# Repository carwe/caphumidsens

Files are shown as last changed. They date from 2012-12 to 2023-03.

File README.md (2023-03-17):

ARCHIVED on github -> migrated to codeberg: https://codeberg.org/carwe/caphumidsens

<b>code not usable due to never debugged bugs</b>

<b>code not usable due to never debugged bugs</b>

<b>code not usable due to never debugged bugs</b>

<b>code not usable due to never debugged bugs</b>

caphumidsens
============
Contains EAGLE-files for a pcb to convert soil moisture into frequency.

There are various revisions of the board:

classic design with NE555
-------------------------

###caphumidsens rev1
This was more or less a test, if the idea is working. It is quite big and unoptimized. Also the design of the capacitator is unnecessary complex.<br>
You need one NE555 (or CMOS-equivalent like TLC555) in SO-8, the other parts are of size 0805. C1=10nF; C2=100nF; R1=R2=120kOhm; D1=1N4148<br>
The chosen values let the output oscillate with around 74kHz, when dry and in air, down to around 4kHz, when the cap-part of the board is put into pure water, if you have chosen the TTL-555.

###caphumidsens rev2
...died an early death and was never physically fabricated.

###caphumidsens rev3
...is space-optimized and the components are nicely placed in a row, the draw-back is, they are too close - unfortuntely I had some of them fabricated, so it needed some fiddling to solder. <b>Do not use this layout.</b> In the discussion about this board some ideas came along: you probably want to measure the humidity in the middle of the soil, at least not directly on the surface, where it varies most. And there should be some kind of safety-margin, you don't want to change the capacitance by moving it slightly in and out of the soil. Next design should adress this.

###caphumidsens rev4
Here the capacitator was moved, so the humidity on the surface is no longer significant. Also the parts, which were too close to each other, got more space between them.

<pre>Measurements (frequency in kHz):
                Rev1/TTL        Rev1/CMOS        Rev3/CMOS        Rev4/CMOS
air              74,9              66,8            91,6              ?
dry soil         73,1              65,3            91,3              ?
half-wet soil    64,0              52,5            73,4              ?
wet soil         13,4              17,8            37,6              ?
water             3,4               ?               ?                ?</pre>

redesign with ATtiny
--------------------

###caphumidsens rev5
Lately I discussed about the project, and it quickly became clear, that it should be possible to connect output-pins of more than one caphumidsens-pcb over a single line with a master-controller. Using a bus has clear advantages (otherwise, you have to use a dedicated line to transport each signal, of course), so I designed a first draft.

With a ATtiny25/45/85 (maybe ATtiny13A too, if the code fits into it - comparator is existent there too, and the pinout is the same) I tried to create a NE555-similar structure. A capacitator is charged to a higher voltage, then discharged to a lower voltage, and a comparator toggles the (dis-)charging.

You have to decide if you want to use the internal voltage reference or not. If yes, you have to sense the voltage with AIN1 and compare it to the internal voltage reference and AIN0 as external voltage reference. If no, you have to sense the voltage with AIN0 and compare it witho two external voltage references on ADC0-ADC3. Some time ago I wrote here you could not compare against the internal reference and the multiplexer at the same time and save a pin - which is true, but you don't need to, it just requires another layout. To use the internal voltage reference for one side of the comparison, you have to have your sense pin as negative side on AIN1, and select the internal reference for the positive side of the AC. Then compare negative side AIN1 with AIN0 as the positive side of the AC. But, this is not what I designed.

I chose to use two external voltage references, created by division of VCC, same as in 555. This way it makes no difference what exact voltage VCC is, it can even change, the resulting frequency is independent. So you sense the voltage on AIN0 as positive side of the AC, and the multiplexer as negative side, and switch the input of the multiplexer as you charge (ADC1) and discharge (ADC2).

Pin 6 is set to VCC or GND to charge or discharge the capacitator, pin 5 senses the voltage and compares it to pin 3 or 7. On pin 1 (and maybe pin 2, if clock-ínput is not needed) you can talk a protocol you like - a simple frequency like the NE555 or something more complex, maybe pulling the line low against a central pull-resistor (I2C-like), sending your ID (stored in EEPROM) followed by the measured capacity. After you have written out a bit of your ID, you read it back, if another sensor is sending too (pulling the line dominates leaving the line alone, so the ID with the most "pulling bits" is the highest, CAN-like). The frequency of the messages is low enough, so that collisions should hardly occur, and if, you simply repeat your message.

Pin 1 is the reset/debugwire-pin too, so you can use debugwire to program the harder part of measuring the capacity, as you don't need the output-pin during this time. I have added small capacitators to even out the reference voltages, if that is necessary.

In the next days, I should receive some of them from the manufacturer.

Update five years later, 2017: yes I got them. and then I forgot them. And, I would not use Eagle anymore. Never again. Took me an hour to find an old version I could use with my licence, it brought me to tears what happened to this program after being bought by Autodesk. Everybody warned me to use this nonfree software, and I thought "whatever... works for me." - then reality hit.

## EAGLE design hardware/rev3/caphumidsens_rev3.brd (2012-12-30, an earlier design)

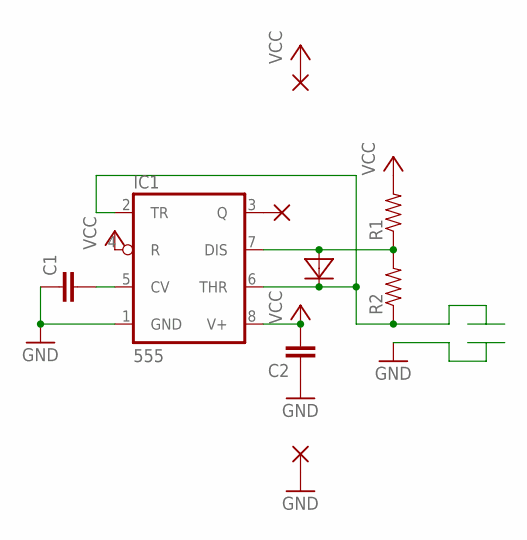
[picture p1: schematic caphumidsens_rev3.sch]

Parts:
C1, C2: CAP0805; 0805
D1: DIODE_0805
GND: WIREPADSMD2,54-5,08; SMD1,27-2,54
IC1: 555; SO08
OUT: WIREPADSMD2,54-5,08; SMD1,27-2,54
R1, R2: RESISTOR0805-RES; 0805
VCC: WIREPADSMD2,54-5,08; SMD1,27-2,54

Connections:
CAP+: D1.1 (C), IC1.2 (TR), IC1.6 (THR), R2.1
GND: C1.1, C2.1, GND.1, IC1.1 (GND)
unnamed: D1.2 (A), IC1.7 (DIS), R1.1, R2.2
unnamed: C1.2, IC1.5 (CV)
unnamed: IC1.3 (Q), OUT.1
VCC: C2.2, IC1.4 (R), IC1.8 (V+), R1.2, VCC.1

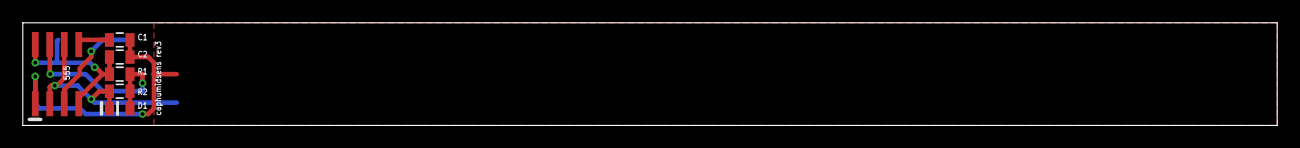
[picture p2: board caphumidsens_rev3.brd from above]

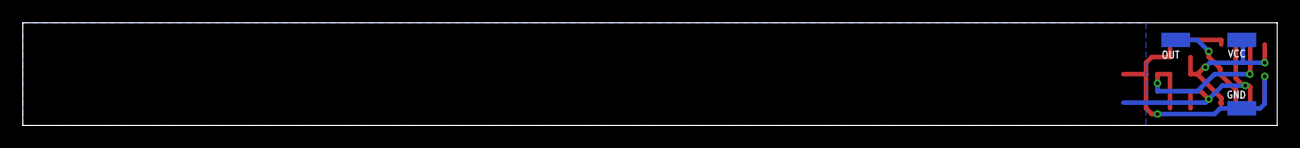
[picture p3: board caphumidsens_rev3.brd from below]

Board: 2 copper layers, 110.0 x 9.0 mm, 9 parts (3 on the bottom side), 6 nets.

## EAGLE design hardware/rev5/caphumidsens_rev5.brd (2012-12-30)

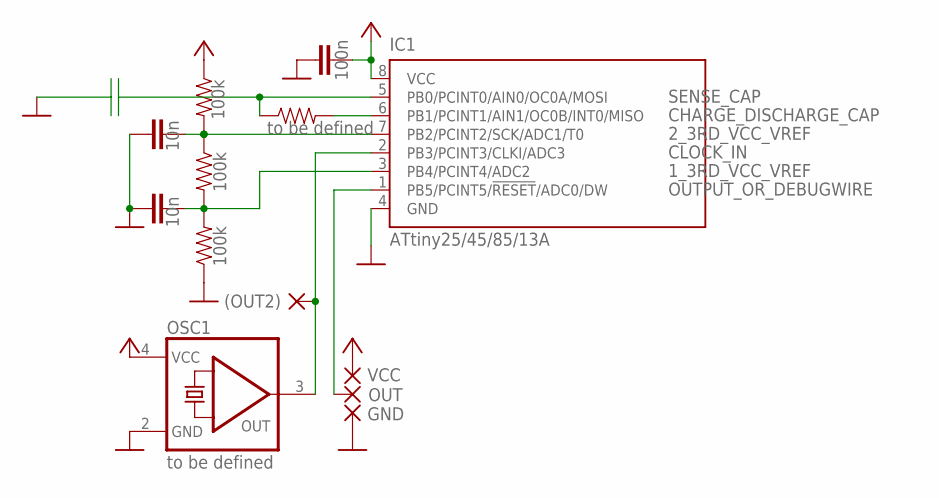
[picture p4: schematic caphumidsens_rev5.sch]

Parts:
(OUT2): WIREPADSMD2,54-5,08; SMD1,27-2,54
C1: 100n; 0805
C2, C3: 10n; 0805
GND: WIREPADSMD2,54-5,08; SMD1,27-2,54
IC1: ATtiny25/45/85/13A; 8S1
OSC1: to be defined; XO32
OUT: WIREPADSMD2,54-5,08; SMD1,27-2,54
R1, R2, R3: 100k; 0805
R4: to be defined; 0805
VCC: WIREPADSMD2,54-5,08; SMD1,27-2,54

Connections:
1_3RD_VCC_VREF: C2.1, IC1.3 (PB4/PCINT4/ADC2), R2.2, R3.2
2_3RD_VCC_VREF: C3.2, IC1.7 (PB2/PCINT2/SCK/ADC1/T0), R1.2, R2.1
CHARGE_DISCHARGE_CAP: IC1.6 (PB1/PCINT1/AIN1/OC0B/INT0/MISO), R4.2
CLOCK_IN: (OUT2).1, IC1.2 (PB3/PCINT3/CLKI/ADC3), OSC1.3 (OUT)
GND: C1.1, C2.2, C3.1, GND.1, IC1.4 (GND), OSC1.2 (GND), R3.1
OUTPUT_OR_DEBUGWIRE: IC1.1 (PB5/PCINT5/!RESET!/ADC0/DW), OUT.1
SENSE_CAP: IC1.5 (PB0/PCINT0/AIN0/OC0A/MOSI), R4.1
VCC: C1.2, IC1.8 (VCC), OSC1.4 (VCC), R1.1, VCC.1

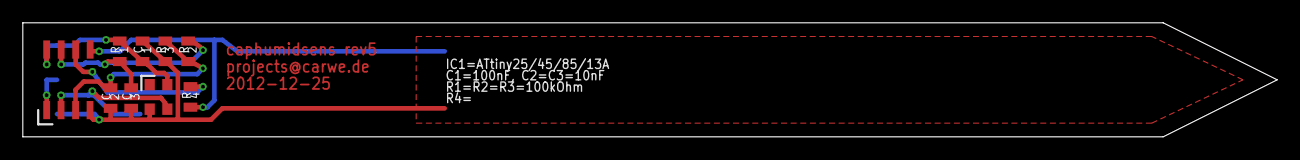
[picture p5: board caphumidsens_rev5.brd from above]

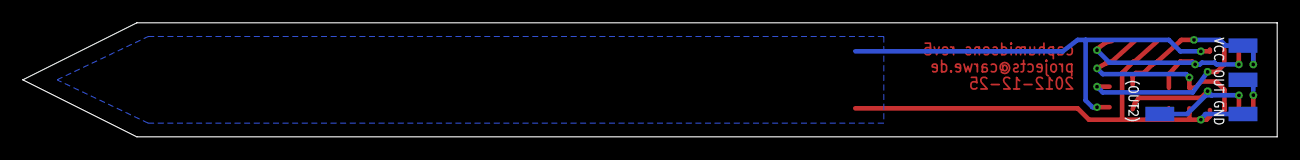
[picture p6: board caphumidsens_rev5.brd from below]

Board: 2 copper layers, 110.0 x 10.0 mm, 13 parts (4 on the bottom side), 8 nets.

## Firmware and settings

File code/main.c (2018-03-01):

// carwe 2017
// code for caphumidsens on Digistumb (ATtiny85)
// with internal bandgap as voltage reference

#define F_CPU 8000000UL
#include <stdbool.h>
#include <avr/io.h>
#include <avr/interrupt.h>
#include <util/delay.h>
#include "BitIO.h"

void AC_setup();
void CAP_charge();
void CAP_discharge();
void ACinterrupt_handling();
void TIM_setup(char);

// on AtTiny25/45/85/13A only Port B exists
#define PIN_CHARGE	2	// as digital output
#define PIN_SENSE	0	// must be on opposite side of multiplexer-input in analog comparator -> AIN0 on AtTiny13A/25/45/85, when usage of internal voltage reference wished
				// must not be AIN0, when two external reference voltages will be used
//#define PIN_VREF_1_3	0	// pin must be usable by analog comparator, maybe via multiplexer // can be substituted with internal voltage reference, when above conditions for PIN_SENSE given
#define PIN_VREF_2_3	1	// pin must be usable by analog comparator, maybe via multiplexer
#define PIN_OUTPUT	3	// as digital output, for $protocol
#define PIN_OUTPUT2	4	// as digital output, for $protocol


volatile char AC_interrupt   = 0;	// 1 when ISR signals voltage equality
volatile int  AC_interrupts  = 0;	// hold the interrupts so far
volatile char CAP_charging   = 1;	// 1==charging, 0==discharging
volatile int  CAP_capacity   = 0;	// hold the interrupts per gate time
         char CAP_countAmax  = 255;	// CAP_countAmax * CAP_countBmax should be CPU cycles per gate time // and define how long charge/discharge-cycles will be added up
         int  CAP_countBmax  = 15000;	// ^
volatile int  CAP_countB     = 0;	// ^
// count from 0 to CAP_countAmax * CAP_countBmax, sum up the oscillations of the charge/discharge-cycle in AC_interrupts, and copy to CAP_capacity at the end

void main() {
	BIT_BOOL_SET(&DDRB,PIN_CHARGE,1);	// set pins as outputs
	BIT_BOOL_SET(&DDRB,PIN_OUTPUT,1);	// ^
	BIT_BOOL_SET(&DDRB,PIN_OUTPUT2,1);	// ^

	BIT_BOOL_SET(&DIDR0,PIN_SENSE,1);	// disable digital input hardware of analog inputs
//	BIT_BOOL_SET(&DIDR0,PIN_VREF_1_3,1);	// ^
	BIT_BOOL_SET(&DIDR0,PIN_VREF_2_3,1);	// ^


	// let the LEDs blink two times to signal the end of the bootloader
	BIT_BOOL_SET(&PORTB,PIN_OUTPUT,0);
	BIT_BOOL_SET(&PORTB,PIN_OUTPUT2,0);
	_delay_ms(100);
	BIT_BOOL_SET(&PORTB,PIN_OUTPUT,1);
	BIT_BOOL_SET(&PORTB,PIN_OUTPUT2,1);
	_delay_ms(100);
	BIT_BOOL_SET(&PORTB,PIN_OUTPUT,0);
	BIT_BOOL_SET(&PORTB,PIN_OUTPUT2,0);
	_delay_ms(100);
	BIT_BOOL_SET(&PORTB,PIN_OUTPUT,1);
	BIT_BOOL_SET(&PORTB,PIN_OUTPUT2,1);
	_delay_ms(100);
	BIT_BOOL_SET(&PORTB,PIN_OUTPUT,0);
	BIT_BOOL_SET(&PORTB,PIN_OUTPUT2,0);
	_delay_ms(100);


	AC_setup();
	TIM_setup(CAP_countAmax);
	CAP_charge();


	int time = 0;
	while (1) {
		char temp1 = 0;
//		BIT_BOOL_SET(&PORTB,PIN_OUTPUT,CAP_charging);
//		BIT_BOOL_SET(&PORTB,PIN_OUTPUT2,(CAP_countB>(CAP_countBmax/2)));
		BIT_BOOL_SET(&PORTB,PIN_OUTPUT,( ACSR & (1<<ACI) ));	// ana_comp interrupt flag
		BIT_BOOL_SET(&PORTB,PIN_OUTPUT2,( SREG & (1<<SREG_I)   ));	// global interrupt enable flag

		time+=1; if (time>=3000) { time=0; }
//		_delay_ms(10);
	}
}



ISR (ANA_COMP_vect) {
	AC_interrupt=1;
	ACinterrupt_handling();
}


void AC_setup() {
	BIT_BOOL_SET(&ACSR,ACD,0);	// enable Analog Comparator
	BIT_BOOL_SET(&ADCSRB,ACME,0);	// disable multiplexer
//	BIT_BOOL_SET(&ACSR,ACIS0,0);	// set to interrupt on any edge
//	BIT_BOOL_SET(&ACSR,ACIS1,0);	// ^
//	BIT_BOOL_SET(&ACSR,ACIE,1);	// enable AC interrupt
	sei();				// enable global interrupts
}


void CAP_charge	() {
	BIT_BOOL_SET(&ACSR,ACIE,0);		// disable AC interrupt

	BIT_BOOL_SET(&ACSR,ACBG,0);		// AIN0 as positive side
	BIT_BOOL_SET(&ACSR,ACIS0,1);		// set to trigger on raising edge
	BIT_BOOL_SET(&ACSR,ACIS1,1);		// ^

	BIT_BOOL_SET(&ACSR,ACIE,1);		// enable AC interrupt
	BIT_BOOL_SET(&PORTB,PIN_CHARGE,1);	// charge
	CAP_charging=1;
}


void CAP_discharge ()
{
	BIT_BOOL_SET(&ACSR,ACIE,0);		// disable AC interrupt

	BIT_BOOL_SET(&ACSR,ACBG,1);		// INTERNAL_VREF as positive side
	BIT_BOOL_SET(&ACSR,ACIS0,0);		// set to trigger on falling edge
	BIT_BOOL_SET(&ACSR,ACIS1,0);		// ^

	BIT_BOOL_SET(&ACSR,ACIE,1);		// enable AC interrupt
	BIT_BOOL_SET(&PORTB,PIN_CHARGE,0);	// discharge
	CAP_charging=0;
}


void ACinterrupt_handling()
{	// handle equality of voltages

	AC_interrupt = 0;
	if (CAP_charging)	// was charging
	{
		AC_interrupts++;
		CAP_discharge();
	} else {		// was discharging
		CAP_charge();
	}
}


void TIM_setup(char CAP_countAmax) {
	BIT_BOOL_SET(&TCCR0B,CS02,0);	// select clock source, 001==CLK without prescaler
	BIT_BOOL_SET(&TCCR0B,CS01,0);	// ^
	BIT_BOOL_SET(&TCCR0B,CS00,1);	// ^
	BIT_BOOL_SET(&TIMSK,TOIE0,1);	// overflow interrupt enable
	TCNT0 = 0;			// reset timer
	OCR0A = CAP_countAmax;		// set to overflow on this value
}


ISR (TIM0_OVF_vect) {
	// handle overflow of timer (every CAP_countAmax)

	CAP_countB++;
	if (CAP_countB >= CAP_countBmax)
	{
		CAP_countB = 0;
		CAP_capacity = AC_interrupts;
		AC_interrupts = 0;
	}
}

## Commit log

2012-09-15 added the eagle-files
    [caphumidsens_rev1.brd, caphumidsens_rev1.sch]
2012-11-05 added rev3-files
    [caphumidsens_rev3.brd, caphumidsens_rev3.sch]
2012-11-06 added rev2-files
    [caphumidsens_rev2.brd, caphumidsens_rev2.sch]
2012-11-11 added files for rev4 rc1
    [caphumidsens_rev4_rc1.brd, caphumidsens_rev4_rc1.sch]
2012-11-12 added files for rev4 rc2
    [caphumidsens_rev4_rc2.brd, caphumidsens_rev4_rc2.sch]
2012-11-12 moved vias closer to their signal's pad's
    [caphumidsens_rev4_rc2.brd]
2012-11-12 moved text to honor border saveguards
    [caphumidsens_rev4_rc2.brd]
2012-11-16 preparing rev4-final
    [caphumidsens_rev4_rc2.brd]
2012-11-16 renamed last layout into final rev4
    [caphumidsens_rev4.brd, caphumidsens_rev4.sch, caphumidsens_rev4_rc1.brd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]
2012-12-07 added files for a new version, not longer with 555 timer, but atmel-microcontroller
    [caphumidsens2_rev1_rc1.brd, caphumidsens2_rev1_rc1.sch, caphumidsens2_rev1_rc2.brd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]
2012-12-10 added redesigned rc3 and updated readme
    [caphumidsens2_rev1_rc3.brd, caphumidsens2_rev1_rc3.sch]
2012-12-11 rc3 finetuned
    [caphumidsens2_rev1_rc3.brd]
2012-12-11 finetuning, misc
    [caphumidsens2_rev1_rc3.brd]
2012-12-12 removed tPlace-Layer from ATtiny
    [caphumidsens2_rev1_rc3.brd, caphumidsens2_rev1_rc3.sch]
2012-12-12 removed tPlace-Layer from 0805-packages
    [caphumidsens2_rev1_rc3.brd, caphumidsens2_rev1_rc3.sch]
2012-12-13 moved via to a better place
    [caphumidsens2_rev1_rc3.brd]
2012-12-13 solder mask misc
    [caphumidsens2_rev1_rc3.brd]
2012-12-13 'improved' routing
    [caphumidsens2_rev1_rc3.brd]
2012-12-13 tName misc
    [caphumidsens2_rev1_rc3.brd]
2012-12-13 added 2nd output-pad, if osc1 isn't needed
    [caphumidsens2_rev1_rc3.brd, caphumidsens2_rev1_rc3.sch]
2012-12-24 misc; renamed 2_rev1_rc3 into _rev5
    [caphumidsens2_rev1_rc1.brd, caphumidsens2_rev1_rc1.sch, caphumidsens2_rev1_rc2.brd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]
2012-12-24 reworked silkscreen
    [caphumidsens_rev5.brd]
2012-12-24 silkscreen misc
    [caphumidsens_rev5.brd]
2012-12-30 switched to v6-fileformat
    [caphumidsens_rev1.brd, caphumidsens_rev1.sch, caphumidsens_rev2.brd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]
2012-12-30 unified layer-colors
    [caphumidsens_rev1.brd, caphumidsens_rev2.brd, caphumidsens_rev3.brd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]
2012-12-30 unified active layers
    [caphumidsens_rev4.brd, caphumidsens_rev5.brd]
2012-12-30 moved files into separate directories
    [caphumidsens_rev1.brd, caphumidsens_rev1.sch, caphumidsens_rev2.brd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]
2017-06-28 move board layouts to subdir
    [caphumidsens_rev1.brd, caphumidsens_rev1.sch, caphumidsens_rev2.brd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]
2017-06-30 bugfix: enable global interrupts
    [main.c]
2017-07-05 replace BIT_CLEAR/BIT_SET with BIT_BOOL_SET
    [main.c]
2017-07-07 fixed logic of analog comparator, still not working as expected
    [main.c]
